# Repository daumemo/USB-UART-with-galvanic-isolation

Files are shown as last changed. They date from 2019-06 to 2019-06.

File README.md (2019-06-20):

# USB-UART-with-galvanic-isolation

A DIY USB-UART adapter for working with devices which need such isolation. Great for programming for e.g. power meter which does not have any isolation from mains voltage. Mainly used for ESP8266 programming, but can be used for any device with UART interface.

You can read more about it:
https://daumemo.com/diy-galvanically-isolated-usb-uart-adapter/

Thing: https://www.thingiverse.com/thing:3703276

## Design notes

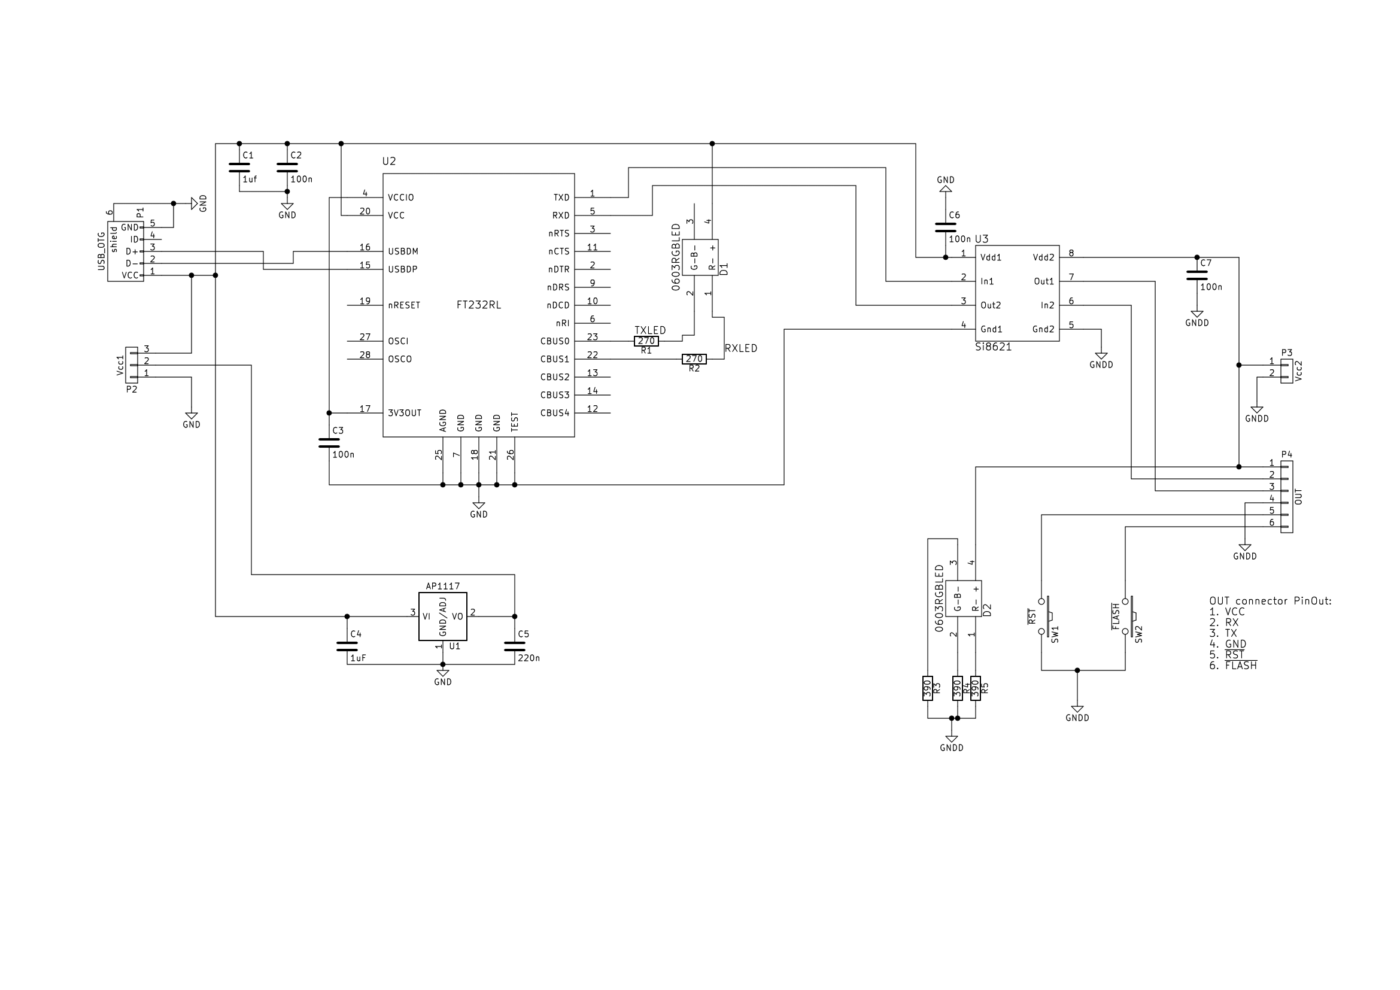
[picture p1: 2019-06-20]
Schematic.png

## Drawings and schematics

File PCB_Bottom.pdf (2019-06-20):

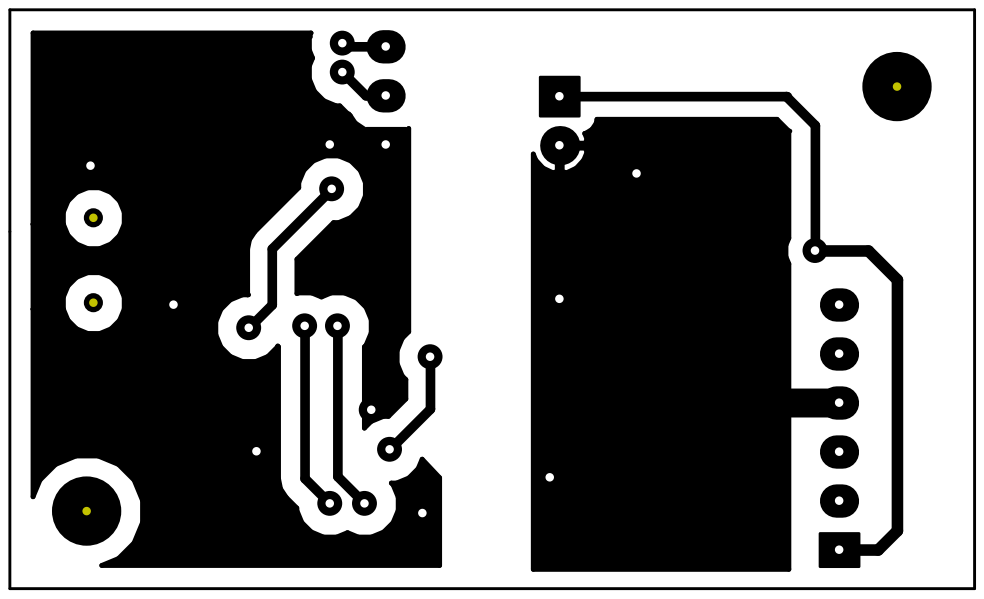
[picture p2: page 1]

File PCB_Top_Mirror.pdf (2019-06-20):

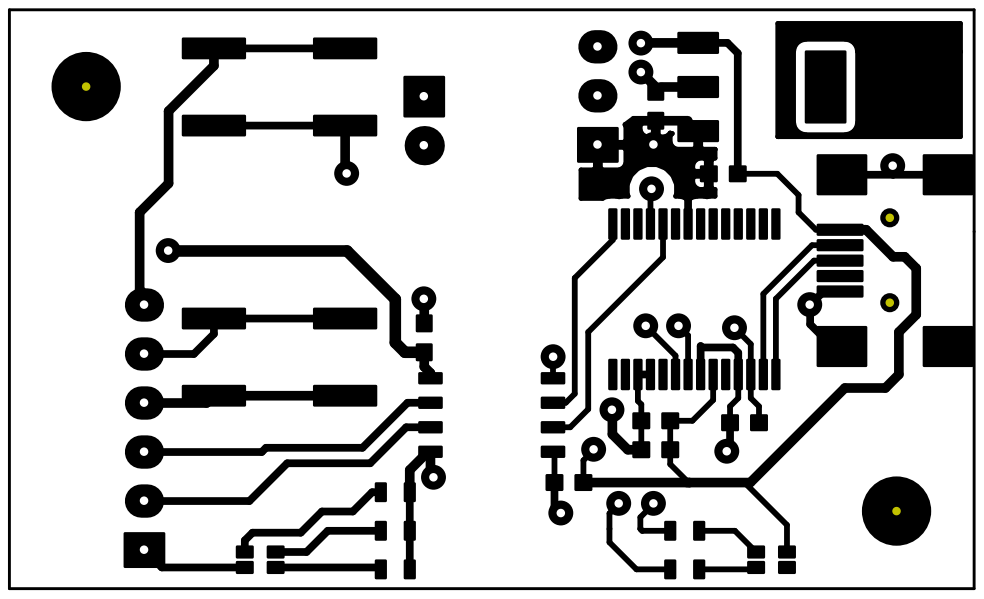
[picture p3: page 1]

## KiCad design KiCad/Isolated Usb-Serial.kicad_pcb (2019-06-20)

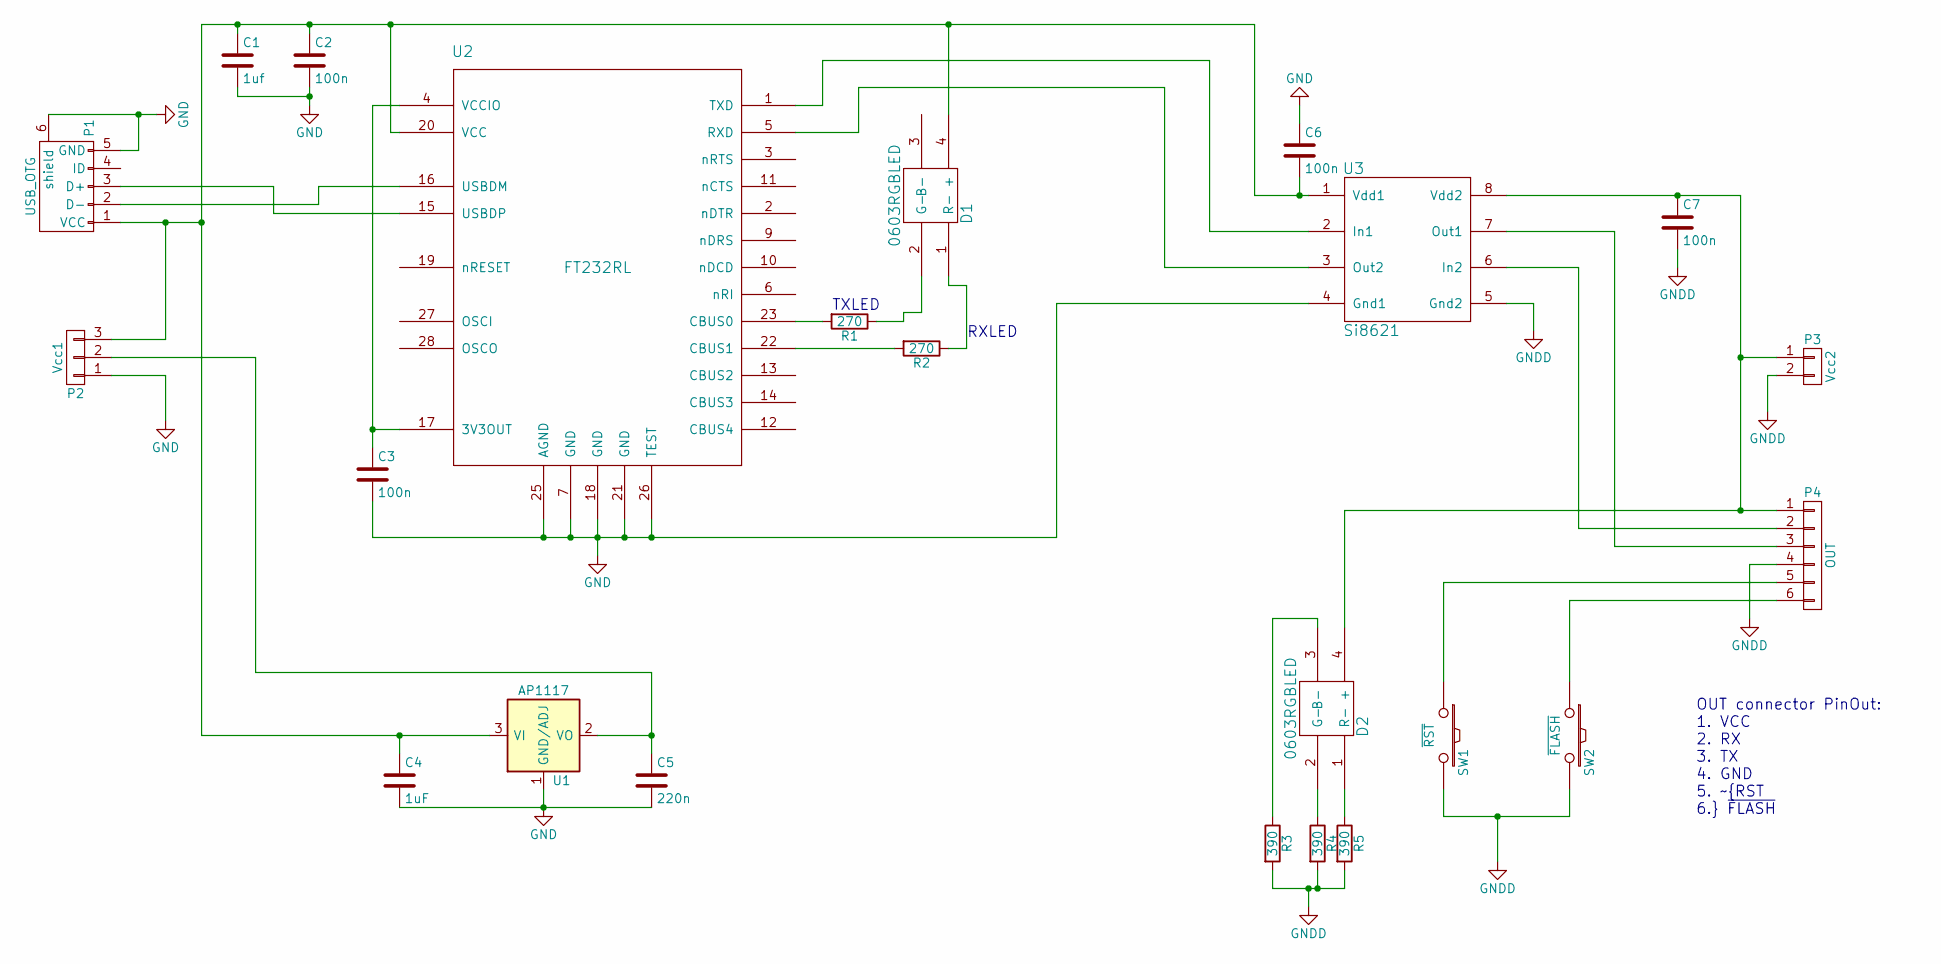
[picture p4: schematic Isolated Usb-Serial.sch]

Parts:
C1: 1uf; C_0603
C2, C3, C6, C7: 100n; C_0603
C4: 1uF; C_0603
C5: 220n; C_0603
D1, D2: 0603RGBLED; 0603_rgb_led
P1: USB_OTG; USB_Mini-B
P2: Vcc1; Pin_Header_Straight_1x03
P3: Vcc2; Pin_Header_Straight_1x02
P4: OUT; Pin_Header_Angled_1x06
R1, R2: 270; R_0603
R3, R4, R5: 390; R_0603
SW1: ~RST; SW_SPST_EVQP0
SW2: ~FLASH; SW_SPST_EVQP0
U1: AP1117; SOT-223
U2: FT232RL; SSOP28
U3: Si8621; SOIC-8-N

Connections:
GND: C1.2, C2.2, C3.2, C4.2, C5.2, C6.1, P1.5 (GND), P1.6 (shield), P2.1, U1.1 (GND/ADJ), U2.7 (GND), U2.18 (GND), U2.21 (GND), U2.25 (AGND), U2.26 (TEST), U3.4 (Gnd1)
GNDD: C7.2, P3.2, P4.4, R3.2, R4.2, R5.2, SW1.2, SW2.2, U3.5 (Gnd2)
unnamed: C1.1, C2.1, C4.1, C6.2, D1.4 (+), P1.1 (VCC), P2.3, U1.3 (VI), U2.20 (VCC), U3.1 (Vdd1)
unnamed: C3.1, U2.4 (VCCIO), U2.17 (3V3OUT)
unnamed: C5.1, P2.2, U1.2 (VO)
unnamed: C7.1, D2.4 (+), P3.1, P4.1, U3.8 (Vdd2)
unnamed: D1.1 (R-), R2.1
unnamed: D1.2 (G-), R1.1
unnamed: D2.1 (R-), R5.1
unnamed: D2.2 (G-), R4.1
unnamed: D2.3 (B-), R3.1
unnamed: P1.2 (D-), U2.16 (USBDM)
unnamed: P1.3 (D+), U2.15 (USBDP)
unnamed: P4.2, U3.6 (In2)
unnamed: P4.3, U3.7 (Out1)
unnamed: P4.5, SW1.1
unnamed: P4.6, SW2.1
unnamed: R1.2, U2.23 (CBUS0)
unnamed: R2.2, U2.22 (CBUS1)
unnamed: U2.1 (TXD), U3.2 (In1)
unnamed: U2.5 (RXD), U3.3 (Out2)

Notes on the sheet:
TXLED
RXLED
OUT connector PinOut: 1. VCC 2. RX 3. TX 4. GND 5. ~RST 6. ~FLASH

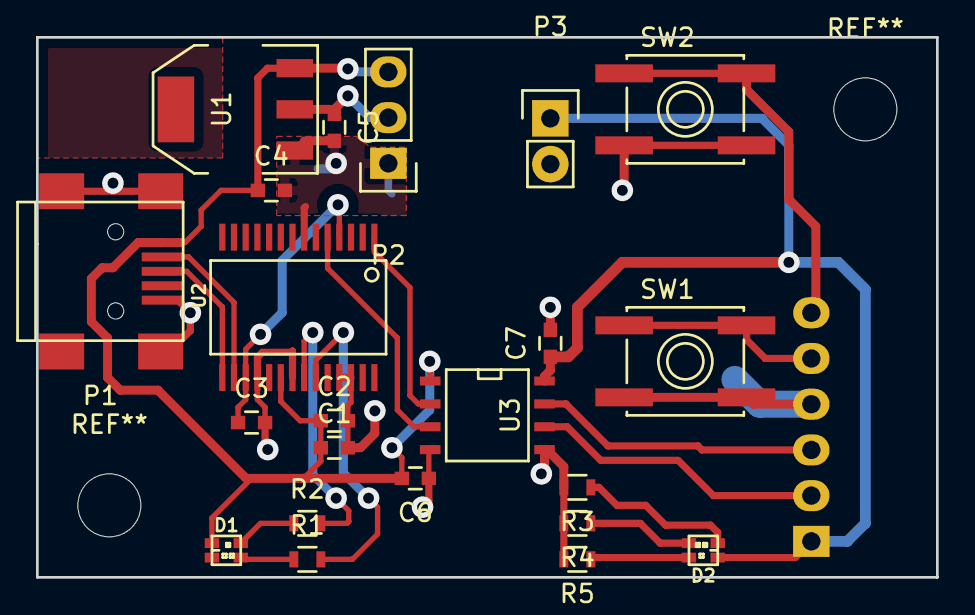
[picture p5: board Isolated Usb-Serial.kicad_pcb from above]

Board: 2 copper layers, 50.0 x 30.0 mm, 23 parts (1 on the bottom side), 21 nets.
